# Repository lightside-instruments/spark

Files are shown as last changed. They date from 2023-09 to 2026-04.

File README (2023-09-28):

Spark is a modular open-source hardware platform
base board and enclosure for use as development kit for programmable
network elements.

The project includes KiCAD project with schematics
and PCB layout sources, BOM, and technical documentation for
production of board with 6x SFP+ interfaces and a 96board
extension interface for the connection of a control board
(FPGA or ASIC)  e.g. Ultra96 from Avnet
and up to 3 optional extension boards:
* glue logic for low speed signals from the optical modules
* GNSS controlled oscillators
* other interface boards, sensor boards, etc.

The project includes also technical documentation for production of
mechanical enclosure - 19 inch 1U rack mountable ESD Acrylic box compatibe
with the base board.

The project is published by Lightside Instruments AS
under TAPR Open Hardware License. Read the LICENSE file
for details.

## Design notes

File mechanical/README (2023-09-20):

Use 4mm acrylic sheets and laser cutter

Blue  - Engrave (or make a pocket with CNC) 2 mm deep for the screw heads - all blue circles.
Black - Engrave logo and port numbers with appropriate settings.
Red   - Cut. There is no clearance fit tollerances (openings are 4 mm) so it is your responsibilitto y correct the slack if you need to.

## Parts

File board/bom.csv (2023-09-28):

Reference | Quantity | Identifier | footprint | Value | Tolerance | Voltage | Current | Power | Mfr | Mfr Part # | Notes
P1 | 1 |  | 96boards:Pin_Header_SMD_2x20_Pitch2mm | CONN_02X20 |  |  |  |  | Molex | 87759-4051
P3 | 1 |  | 96boards:61083-063400LF | CONN_02X30 |  |  |  |  | Amphenol | 61083-064400LF
J1_1;J2_1;J3_1;J4_1;J5_1;J6_1 | 6 |  | spark:molex-sfp-plus-747540-101 | SFP+ |  |  |  |  |  | 74754-0101
J1;J2;J3;J4;J5;J6 | 6 |  | spark:molex-sfp-plus-747540-101 | SFP+ |  |  |  |  |  | 74441-0001
J1_2;J2_2;J3_2;J4_2;J5_2;J6_2 | 6 |  | spark:molex-sfp-plus-747540-101 | SFP+ |  |  |  |  |  | 74754-0011
R102;R103;R105;R106;R107;R202;R203;R205;R206;R207;R302;R303;R305;R306;R307;R402;R403;R405;R406;R407;R502;R503;R505;R506;R507;R602;R603;R605;R606;R607;R9 | 31 |  | Resistor_SMD:R_0402_1005Metric | 10K |  |  |  |  |  | CRCW040210K0FKEDC
C102;C104;C101;C103;C202;C204;C201;C203;C302;C304;C301;C303;C402;C404;C401;C403;C502;C504;C501;C503;C602;C604;C601;C603 | 24 |  | Capacitor_SMD:C_0402_1005Metric | 100nF |  |  |  |  |  | 885012205037
J10 | 1 |  | spark:PJ1-021-SMT-TR | Barrel_Jack |  |  |  |  |  | PJ1-021-SMT-TR
L102;L101;L202;L201;L302;L301;L402;L401;L502;L501;L602;L601 | 12 |  | Inductor_SMD:L_1210_3225Metric | 4.7uH |  |  |  |  |  | CM322522-4R7JL
C106;C105;C8;C206;C205;C306;C305;C406;C405;C506;C505;C606;C605 | 13 |  | Capacitor_SMD:C_1210_3225Metric | 22uF |  | >=16V |  |  |  | F931C226MBAAJ6 | TAJB226M016SNJ
D101;D201;D301;D401;D501;D601 | 6 |  | LED_SMD:LED_0402_1005Metric | ADM_LED |  |  |  |  |  | 150040VS73240
R101;R104;R201;R204;R301;R304;R401;R404;R501;R504;R601;R604 | 12 |  | Resistor_SMD:R_0402_1005Metric | 1K |  |  |  |  |  | RR0510P-102-D
D102;D202;D302;D402;D502;D602 | 6 |  | LED_SMD:LED_0402_1005Metric | ALARM_LED |  |  |  |  |  | 150040VS73240
C7 | 1 |  | Capacitor_Tantalum_SMD:CP_EIA-7343-31_Kemet-D | 330uF |  |  |  |  |  | T491D227M016AT
C9 | 1 |  | Capacitor_Tantalum_SMD:CP_EIA-7343-31_Kemet-D | 220uF |  |  |  |  |  | T491D227M016AT
P2 | 1 |  | 96boards:Socket_Strip_SMD_2x20_Pitch2mm | Conn_02x20_Odd_Even |  |  |  |  | Amphenol | 55510-140LF
J8_1;J8_2 | 2 |  | Connector_PinHeader_2.00mm:PinHeader_2x30_P2.00mm_Vertical_SMD | Conn_02x30_Odd_Even |  |  |  |  | Samtec | TMM-130-01-L-D-SM | Or 2x TMM-115-01-L-D-SM
P5;P4 | 2 |  | Connector_PinHeader_2.54mm:PinHeader_2x20_P2.54mm_Vertical_SMD | Conn_02x20_Odd_Even |  |  |  |  | Harwin | M20-7812045
SW2 | 1 |  | Button_Switch_SMD:SW_DIP_SPSTx06_Slide_Omron_A6H-6101_W6.15mm_P1.27mm | SW_DIP_x06 |  |  |  |  |  | A6H-6101
P6 | 1 |  | spark:5177983-2 | CONN_02X30 |  |  |  |  | TE CONNECTIVITY | 1-5177983-2
SW1 | 1 |  | Button_Switch_THT:SW_Tactile_SPST_Angled_PTS645Vx83-2LFS | SW_Push |  |  |  |  |  | PTS645VK582LFS
R1 | 1 |  | Resistor_SMD:R_0402_1005Metric | 13.3K |  |  |  |  |  | ERA-2AEB1332X
U1 | 1 |  |  |  |  |  |  |  |  | LTM4624IY#PBF
U2 | 1 |  | Package_SO:SO-8_3.9x4.9mm_P1.27mm | PCA9306 |  |  |  |  |  | PCA9306D
R3;R4;R6;R7 | 4 |  | Resistor_SMD:R_0402_1005Metric | 4K7 |  |  |  |  |  | CRCW04024K70FKED
R5 | 1 |  | Resistor_SMD:R_0402_1005Metric | 200K |  |  |  |  |  | AC0402FR-7W200KL
J14;J15;J9;J11 | 4 |  | PinSocket_2x07_P2.00mm_Vertical_SMD | Conn_02x07_Odd_Even |  |  |  |  |  | M20-7810745
SW4 | 1 |  | Connector_PinHeader_2.54mm:PinHeader_1x02_P2.54mm_Vertical | SW_DIP_x01 |  |  |  |  |  | 87224-2
R10 | 1 |  | Resistor_SMD:R_0402_1005Metric | 7K15 |  |  |  |  |  | CR0402-FX-7151GLF

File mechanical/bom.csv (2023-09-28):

Reference | Quantity | Mfr | Mfr Part # | Description
M1 | 4 | Wurth | 971080154 | Standoff 8mm_w_6mm_ext_thread
M2 | 10 | Wurth | 970060154 | Standoff Female-Female 6mm
M3 | 4 | Wurth | 971060154 | Standoff 6mm_w_6mm_ext_thread
M4 | 8 | Essentra | 302208059935 | Standoff Female-Female 8mm
M5 | 10 | Wurth | SCR-RSD-DIN7985-4.8-H1-(A2K)-M2,5X4 | Pan head screw M2.5 4mm

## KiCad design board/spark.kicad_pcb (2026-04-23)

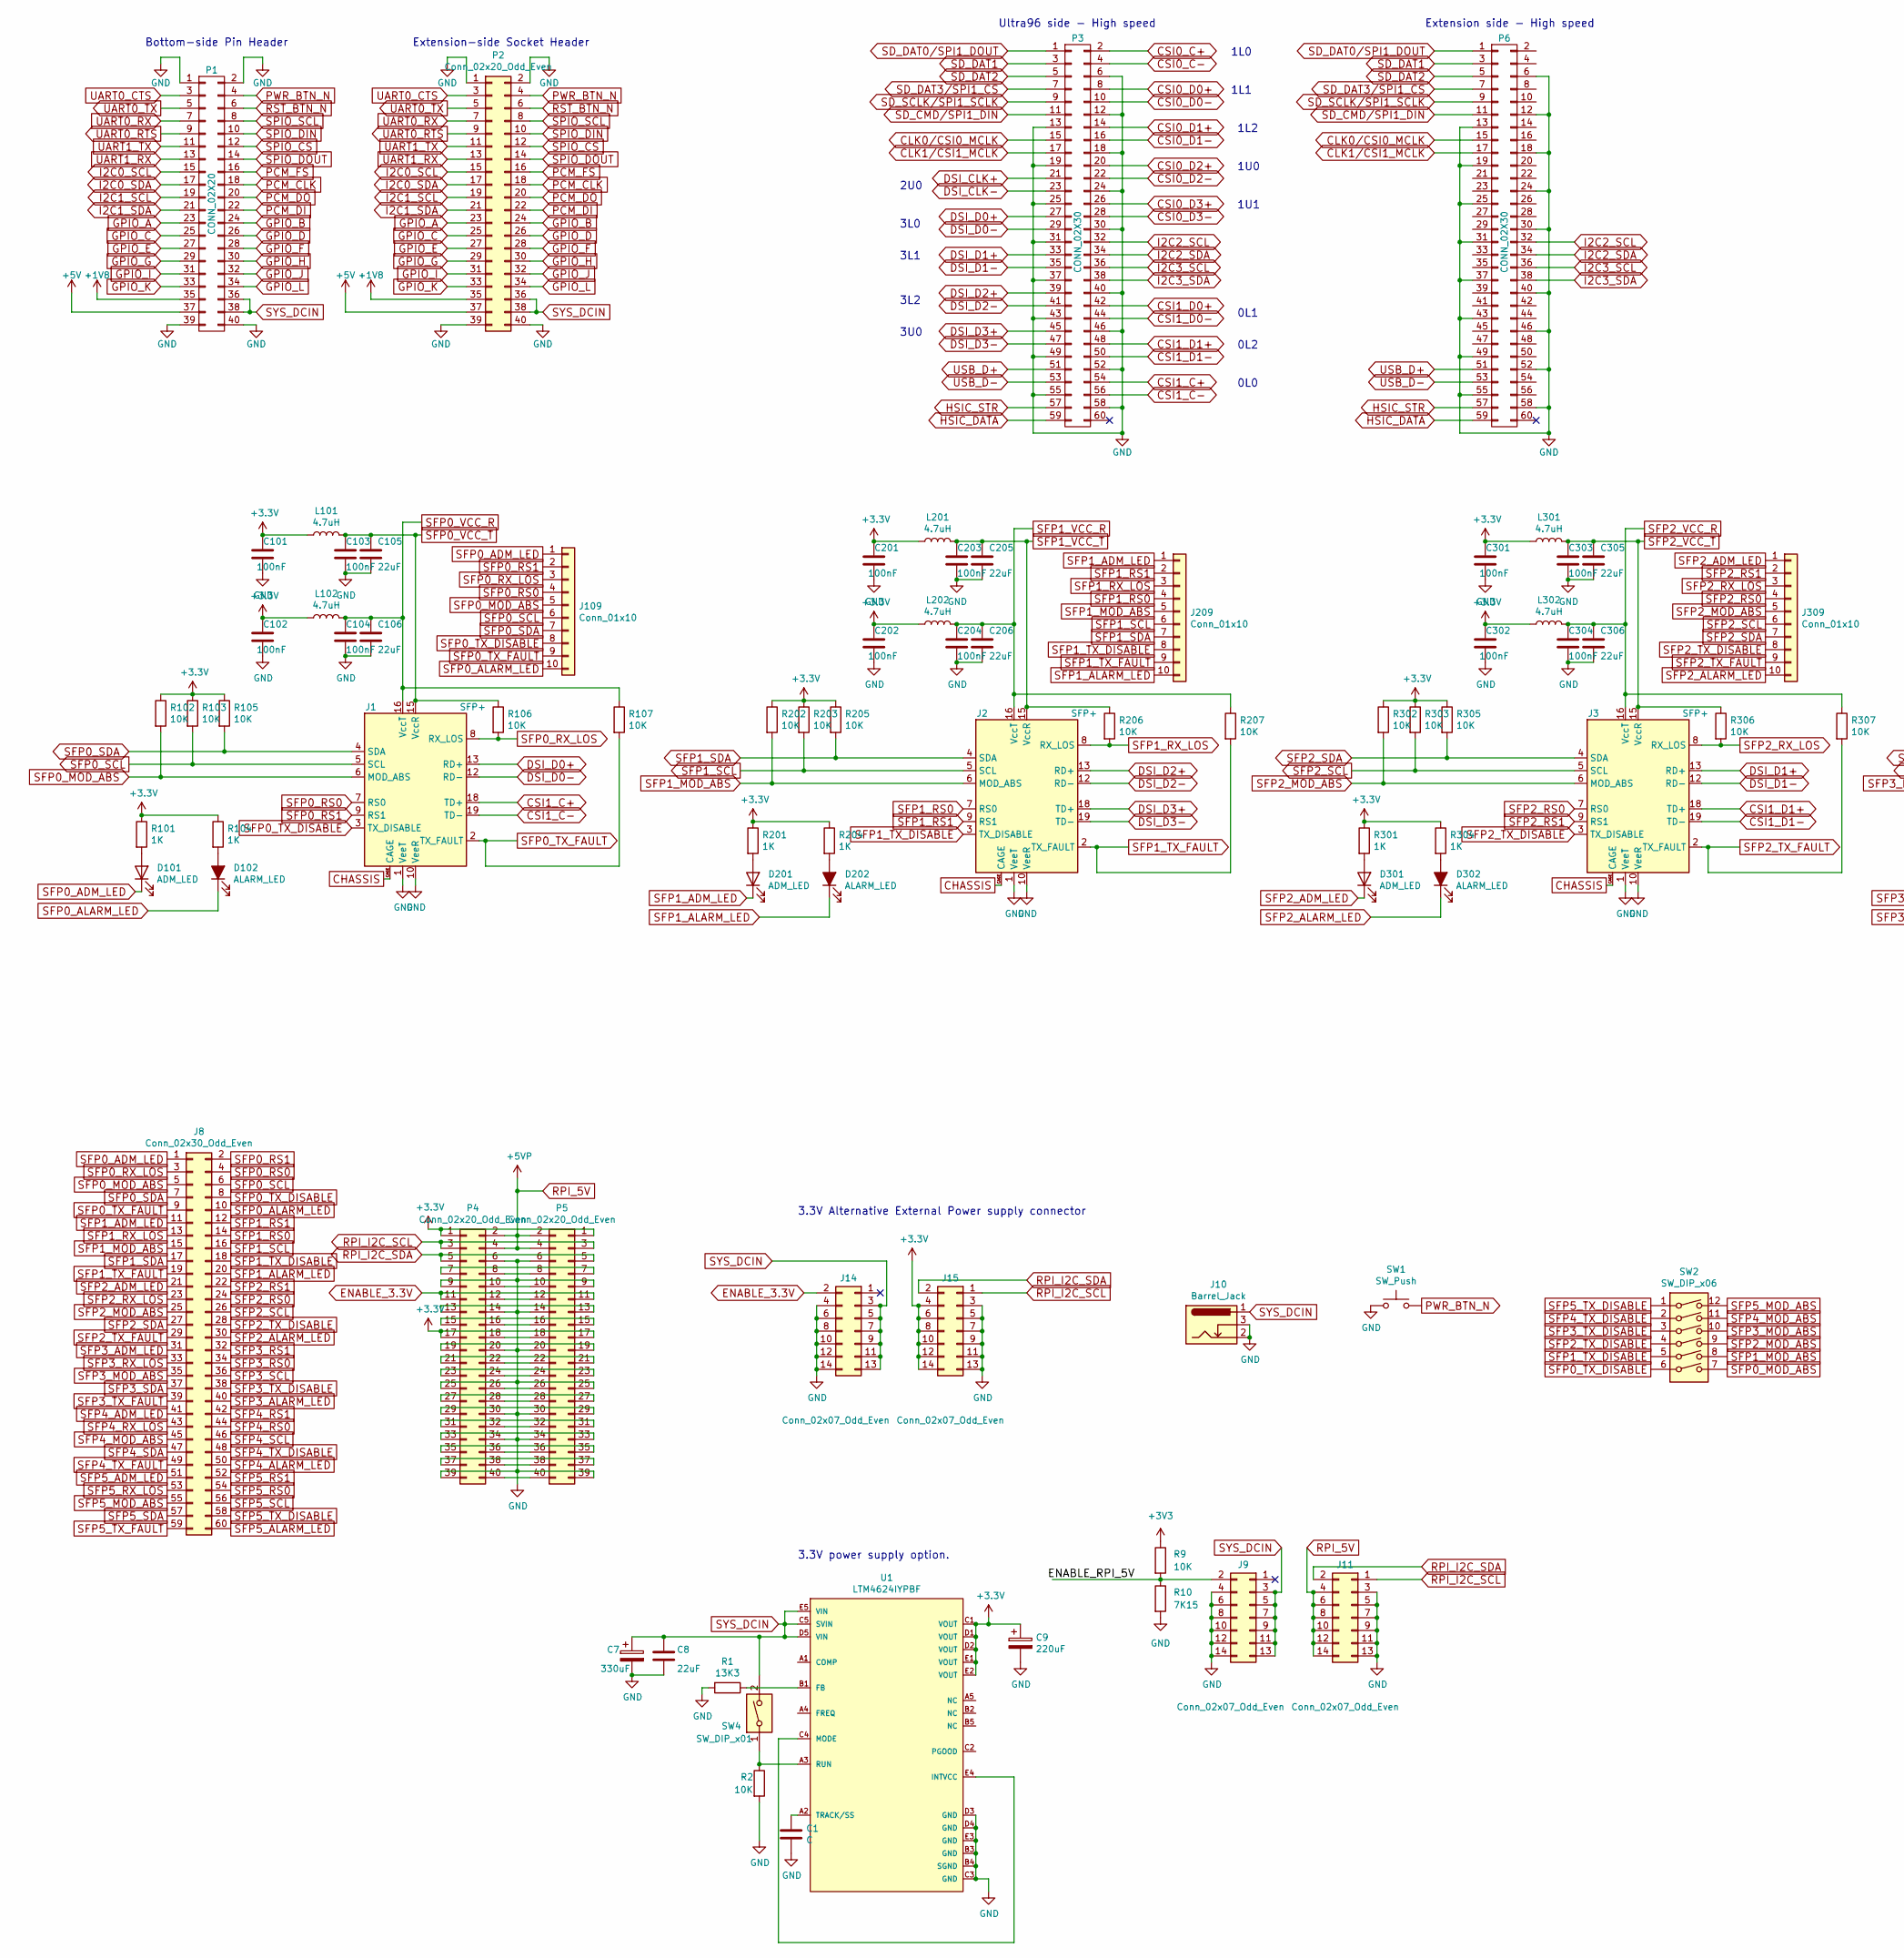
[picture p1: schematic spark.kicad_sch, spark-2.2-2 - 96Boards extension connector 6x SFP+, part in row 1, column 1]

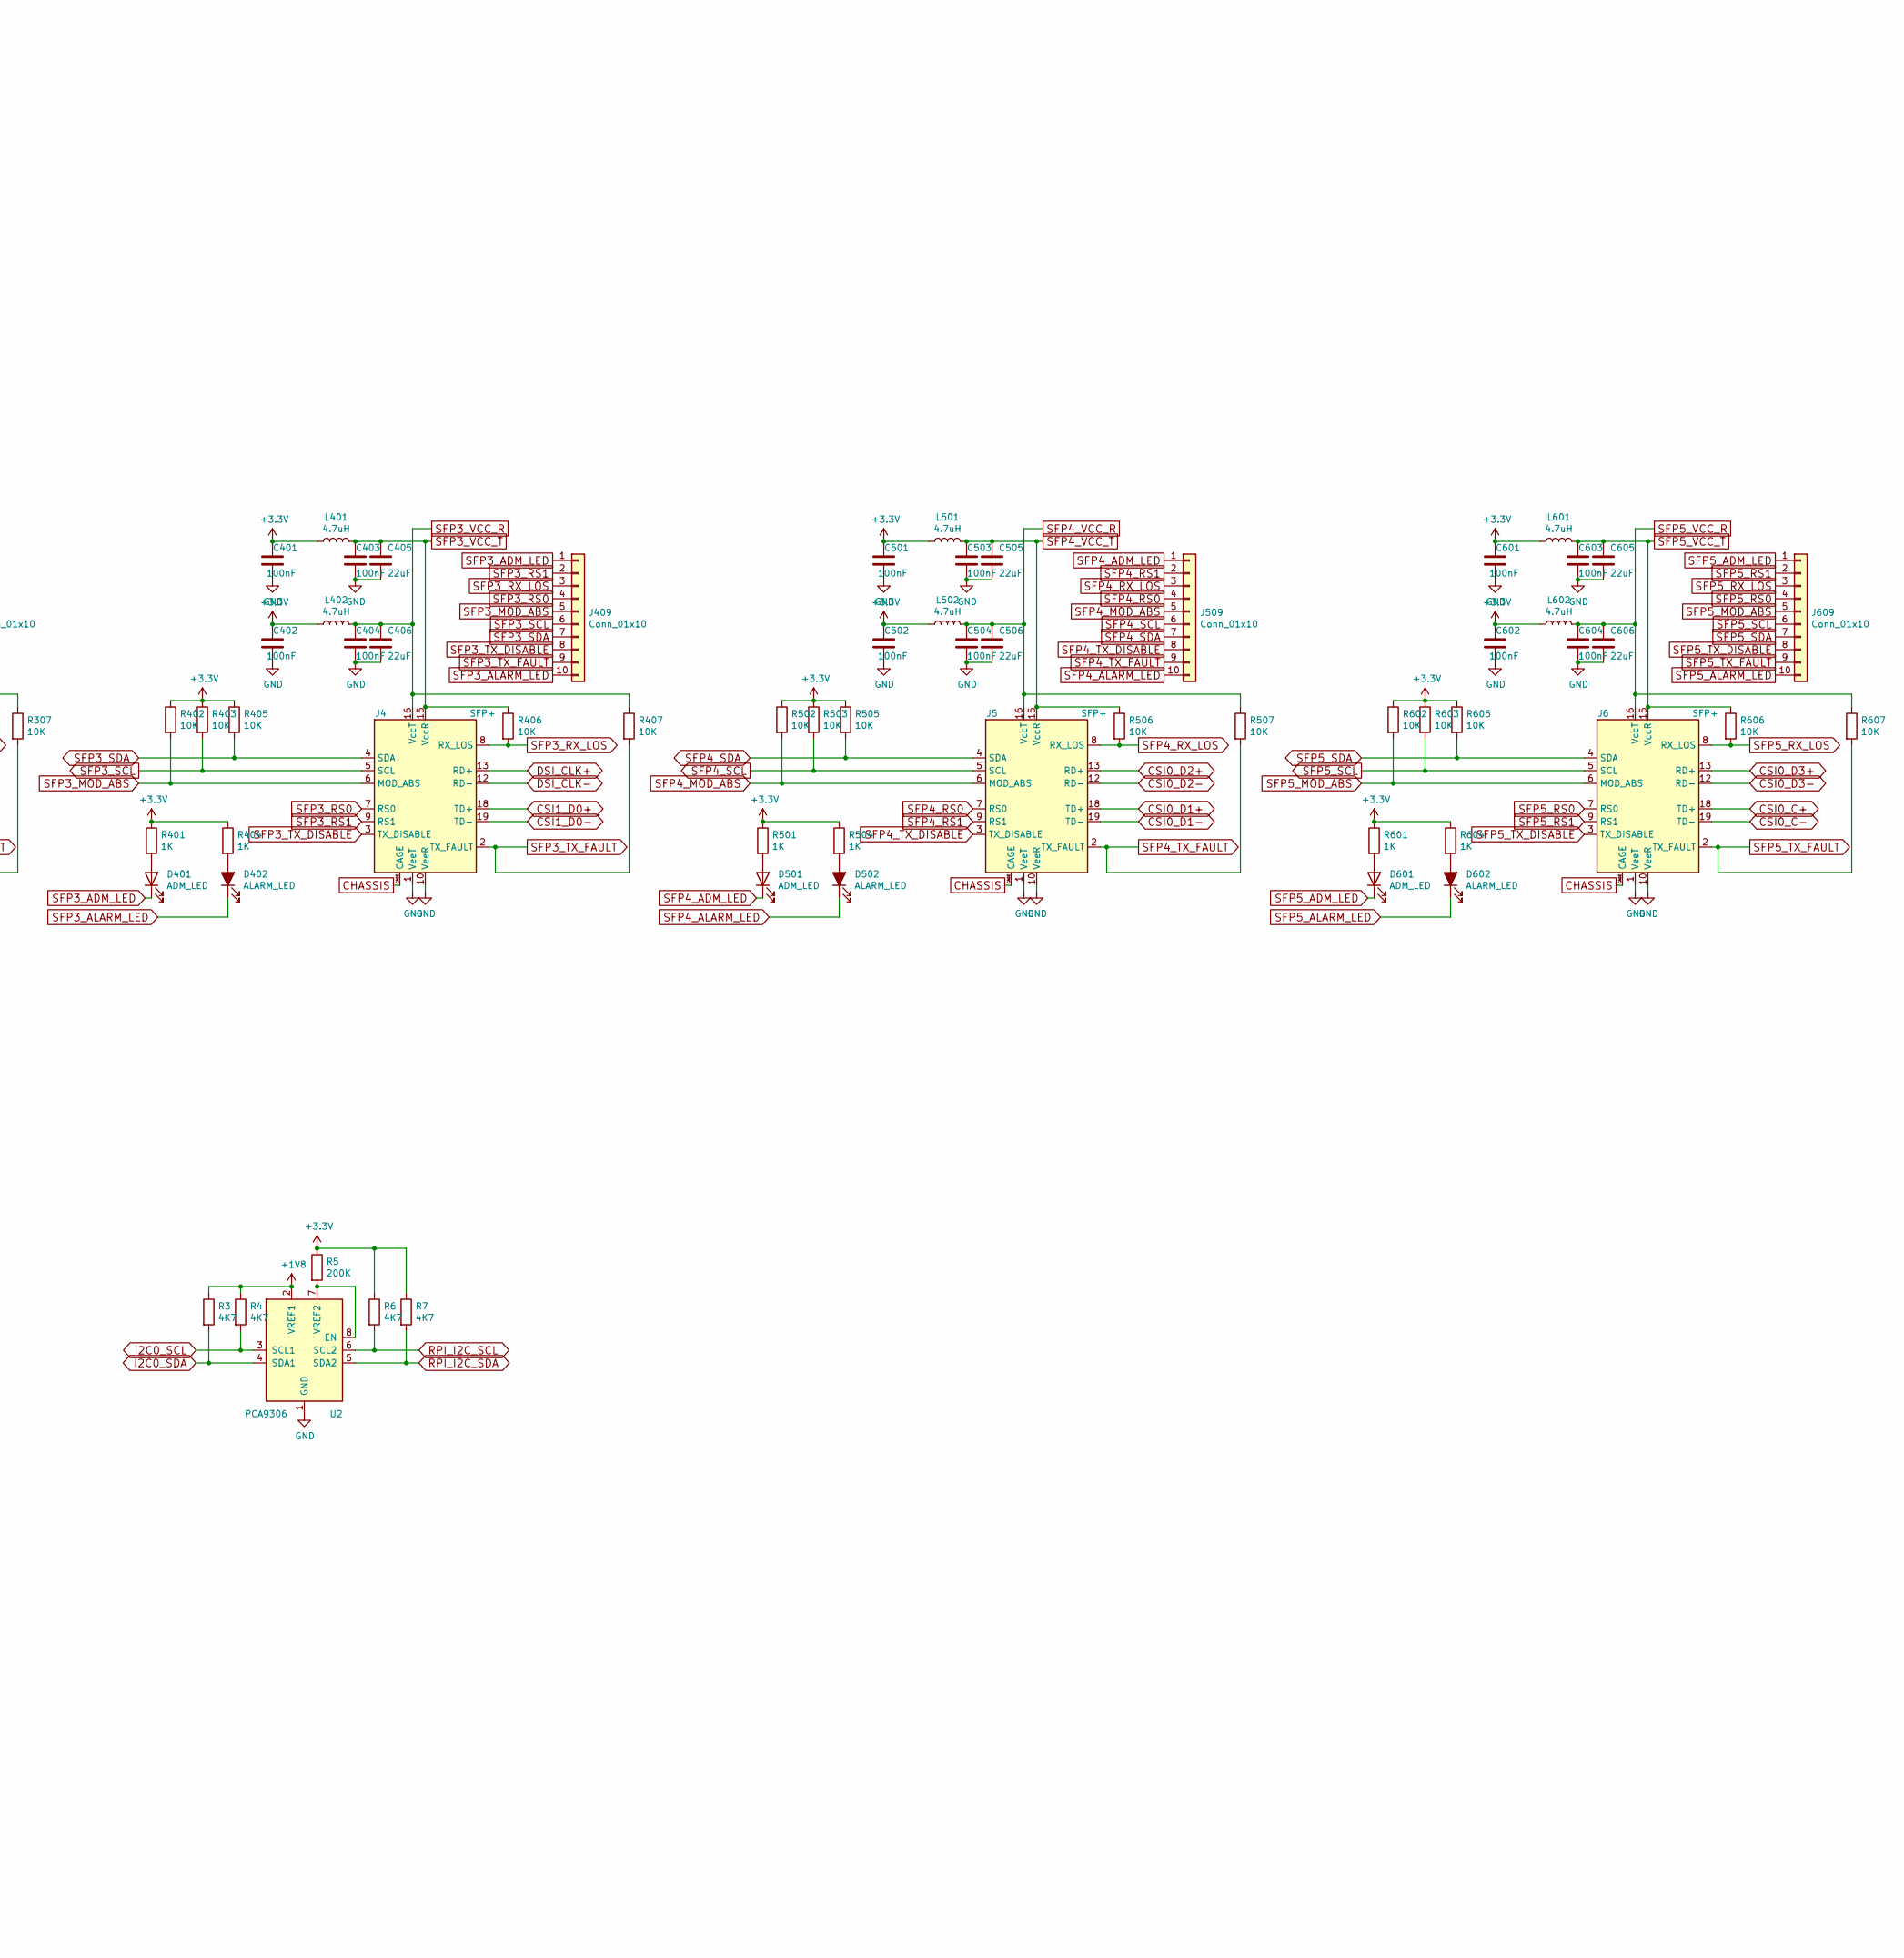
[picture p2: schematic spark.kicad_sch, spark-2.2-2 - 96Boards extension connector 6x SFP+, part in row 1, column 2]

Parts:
C1: C; C_0402_1005Metric
C7: 330uF; CP_EIA-7343-31_Kemet-D
C8, C105, C106, C205, C206, C305, C306, C405, C406, C505, C506, C605, C606: 22uF; CP_EIA-3528-21_Kemet-B; Mfr Part # TAJB226K016TNJ
C9: 220uF; CP_EIA-7343-31_Kemet-D
C101, C102, C103, C104, C201, C202, C203, C204, C301, C302, C303, C304, C401, C402, C403, C404, C501, C502, C503, C504, C601, C602, C603, C604: 100nF; C_0402_1005Metric
D101, D201, D301, D401, D501, D601: ADM_LED; LED_0402_1005Metric
D102, D202, D302, D402, D502, D602: ALARM_LED; LED_0402_1005Metric
J1, J2, J3, J4, J5, J6: SFP+; molex-sfp-plus-747540-101
J8: Conn_02x30_Odd_Even; PinHeader_2x30_P2.00mm_Vertical_SMD
J9, J11, J14, J15: Conn_02x07_Odd_Even; PinSocket_2x07_P2.00mm_Vertical_SMD
J10: Barrel_Jack; PJ1-021-SMT-TR
J109, J209, J309, J409, J509, J609: Conn_01x10; sfp_header
L101, L102, L201, L202, L301, L302, L401, L402, L501, L502, L601, L602: 4.7uH; L_1210_3225Metric
P1: CONN_02X20; Pin_Header_SMD_2x20_Pitch2mm; Mfr Part # 87759-4051
P2: Conn_02x20_Odd_Even; Socket_Strip_SMD_2x20_Pitch2mm_Alignment_Pin
P3: CONN_02X30; 61083-063400LF; Mfr Part # 61083-064400LF
P4, P5: Conn_02x20_Odd_Even; PinSocket_2x20_P2.54mm_Vertical_Inverted_SMD_Alignment_Pin
P6: CONN_02X30; 5177983-2; Mfr Part # 5177983-2
R1: 13K3; R_0402_1005Metric
R2, R9, R102, R103, R105, R106, R107, R202, R203, R205, R206, R207, R302, R303, R305, R306, R307, R402, R403, R405, R406, R407, R502, R503, R505, R506, R507, R602, R603, R605, R606, R607: 10K; R_0402_1005Metric
R3, R4, R6, R7: 4K7; R_0402_1005Metric
R5: 200K; R_0402_1005Metric
R10: 7K15; R_0402_1005Metric
R101, R104, R201, R204, R301, R304, R401, R404, R501, R504, R601, R604: 1K; R_0402_1005Metric
SW1: SW_Push; SW_Tactile_SPST_Angled_PTS645Vx83-2LFS; Mfr Part # PTS645VK582LFS
SW2: SW_DIP_x06; SW_DIP_SPSTx06_Slide_Omron_A6H-6101_W6.15mm_P1.27mm; Mfr Part # A6H-6101
SW4: SW_DIP_x01; PinHeader_1x02_P2.54mm_Vertical
U1: LTM4624IYPBF; Analog_Devices_Inc-BGA-0-05-08-1905_Rev_C-0; output voltage 0.6-5.5V; mouser part number 584-LTM4624IY#PBF; digikey description DC DC CONVERTER 0.6-5.5V 4A
U2: PCA9306; SO-8_3.9x4.9mm_P1.27mm

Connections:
+1V8: P1.35, P2.35, R3.1, R4.1, U2.2 (VREF1)
+5V: P1.37, P2.37
/ENABLE_RPI_5V: J9.2, R9.2, R10.1
CHASSIS: J1.CAGE, J2.CAGE, J3.CAGE, J4.CAGE, J5.CAGE, J6.CAGE
CLK0/CSI0_MCLK: P3.15, P6.15
CLK1/CSI1_MCLK: P3.17, P6.17
CSI0_C+: J6.18 (TD+), P3.2
CSI0_C-: J6.19 (TD-), P3.4
CSI0_D0+: P3.8
CSI0_D0-: P3.10
CSI0_D1+: J5.18 (TD+), P3.14
CSI0_D1-: J5.19 (TD-), P3.16
CSI0_D2+: J5.13 (RD+), P3.20
CSI0_D2-: J5.12 (RD-), P3.22
CSI0_D3+: J6.13 (RD+), P3.26
CSI0_D3-: J6.12 (RD-), P3.28
CSI1_C+: J1.18 (TD+), P3.54
CSI1_C-: J1.19 (TD-), P3.56
CSI1_D0+: J4.18 (TD+), P3.42
CSI1_D0-: J4.19 (TD-), P3.44
CSI1_D1+: J3.18 (TD+), P3.48
CSI1_D1-: J3.19 (TD-), P3.50
DSI_CLK+: J4.13 (RD+), P3.21
DSI_CLK-: J4.12 (RD-), P3.23
DSI_D0+: J1.13 (RD+), P3.27
DSI_D0-: J1.12 (RD-), P3.29
DSI_D1+: J3.13 (RD+), P3.33
DSI_D1-: J3.12 (RD-), P3.35
DSI_D2+: J2.13 (RD+), P3.39
DSI_D2-: J2.12 (RD-), P3.41
DSI_D3+: J2.18 (TD+), P3.45
DSI_D3-: J2.19 (TD-), P3.47
ENABLE_3.3V: J14.2, P4.11, P5.11
GND: C1.2, C7.2, C8.2, C9.2, C101.2, C102.2, C103.2, C104.2, C105.2, C106.2, C201.2, C202.2, C203.2, C204.2, C205.2, C206.2, C301.2, C302.2, C303.2, C304.2, C305.2, C306.2, C401.2, C402.2, C403.2, C404.2, C405.2, C406.2, C501.2, C502.2, C503.2, C504.2, C505.2, C506.2, C601.2, C602.2, C603.2, C604.2, C605.2, C606.2, J1.1 (VeeT), J1.10 (VeeR), J1.11 (VeeR), J1.14 (VeeR), J1.17 (VeeT), J1.20 (VeeT), J2.1 (VeeT), J2.10 (VeeR), J2.11 (VeeR), J2.14 (VeeR), J2.17 (VeeT), J2.20 (VeeT), J3.1 (VeeT), J3.10 (VeeR), J3.11 (VeeR), J3.14 (VeeR), J3.17 (VeeT), J3.20 (VeeT), J4.1 (VeeT), J4.10 (VeeR), J4.11 (VeeR), J4.14 (VeeR), J4.17 (VeeT), J4.20 (VeeT), J5.1 (VeeT), J5.10 (VeeR), J5.11 (VeeR), J5.14 (VeeR), J5.17 (VeeT), J5.20 (VeeT), J6.1 (VeeT), J6.10 (VeeR), J6.11 (VeeR), J6.14 (VeeR), J6.17 (VeeT), J6.20 (VeeT), J9.4, J9.6, J9.8, J9.10, J9.12, J9.14, J10.2, J10.3, J11.3, J11.5, J11.7, J11.9, J11.11, J11.13, J14.4, J14.6, J14.8, J14.10, J14.12, J14.14, J15.3, J15.5, J15.7, J15.9, J15.11, J15.13, P1.1, P1.2, P1.39, P1.40, P2.1, P2.2, P2.39, P2.40, P3.6, P3.12, P3.13, P3.18, P3.19, P3.24, P3.25, P3.30, P3.31, P3.37, P3.40, P3.43, P3.46, P3.49, P3.52, P3.55, P3.58, P4.6, P4.9, P4.14, P4.20, P4.25, P4.30, P4.34, P4.39, P5.6, P5.9, P5.14, P5.20, P5.25, P5.30, P5.34, P5.39, P6.6, P6.12, P6.13, P6.18, P6.19, P6.24, P6.25, P6.30, P6.31, P6.37, P6.40, P6.43, P6.46, P6.49, P6.52, P6.55, P6.58, R1.2, R2.2, R10.2, SW1.1, U1.B3 (GND), U1.B4 (SGND), U1.C3 (GND), U1.D3 (GND), U1.D4 (GND), U1.E3 (GND), U2.1 (GND)
GPIO_A: P1.23, P2.23
GPIO_B: P1.24, P2.24
GPIO_C: P1.25, P2.25
GPIO_D: P1.26, P2.26
GPIO_E: P1.27, P2.27
GPIO_F: P1.28, P2.28
GPIO_G: P1.29, P2.29
GPIO_H: P1.30, P2.30
GPIO_I: P1.31, P2.31
GPIO_J: P1.32, P2.32
GPIO_K: P1.33, P2.33
GPIO_L: P1.34, P2.34
HSIC_DATA: P3.59, P6.59
HSIC_STR: P3.57, P6.57
I2C0_SCL: P1.15, P2.15, R4.2, U2.3 (SCL1)
I2C0_SDA: P1.17, P2.17, R3.2, U2.4 (SDA1)
I2C1_SCL: P1.19, P2.19
I2C1_SDA: P1.21, P2.21
I2C2_SCL: P3.32, P6.32
I2C2_SDA: P3.34, P6.34
I2C3_SCL: P3.36, P6.36
I2C3_SDA: P3.38, P6.38
unnamed: C1.1, U1.A2 (TRACK/SS)
unnamed: D101.2 (A), R101.2
unnamed: D102.2 (A), R104.2
unnamed: D201.2 (A), R201.2
unnamed: D202.2 (A), R204.2
unnamed: D301.2 (A), R301.2
unnamed: D302.2 (A), R304.2
unnamed: D401.2 (A), R401.2
unnamed: D402.2 (A), R404.2
unnamed: D501.2 (A), R501.2
unnamed: D502.2 (A), R504.2
unnamed: D601.2 (A), R601.2
unnamed: D602.2 (A), R604.2
unnamed: P4.7, P5.7
unnamed: P4.8, P5.8
unnamed: P4.10, P5.10
unnamed: P4.12, P5.12
unnamed: P4.13, P5.13
unnamed: P4.15, P5.15
unnamed: P4.16, P5.16
unnamed: P4.18, P5.18
unnamed: P4.19, P5.19
unnamed: P4.21, P5.21
unnamed: P4.22, P5.22
unnamed: P4.23, P5.23
unnamed: P4.24, P5.24
unnamed: P4.26, P5.26
unnamed: P4.27, P5.27
unnamed: P4.28, P5.28
unnamed: P4.29, P5.29
unnamed: P4.31, P5.31
unnamed: P4.32, P5.32
unnamed: P4.33, P5.33
unnamed: P4.35, P5.35
unnamed: P4.36, P5.36
unnamed: P4.37, P5.37
unnamed: P4.38, P5.38
unnamed: P4.40, P5.40
unnamed: R1.1, U1.B1 (FB)
unnamed: R2.1, SW4.1, U1.A3 (RUN)
unnamed: R5.2, U2.7 (VREF2), U2.8 (EN)
unnamed: U1.C4 (MODE), U1.E4 (INTVCC)
PCM_CLK: P1.18, P2.18
PCM_DI: P1.22, P2.22
PCM_DO: P1.20, P2.20
PCM_FS: P1.16, P2.16
PWR_BTN_N: P1.4, P2.4, SW1.2
RPI_5V: J11.4, J11.6, J11.8, J11.10, J11.12, J11.14, P4.2, P4.4, P5.2, P5.4
RPI_I2C_SCL: J11.1, J15.1, P4.3, P5.3, R6.2, U2.6 (SCL2)
RPI_I2C_SDA: J11.2, J15.2, P4.5, P5.5, R7.2, U2.5 (SDA2)
RST_BTN_N: P1.6, P2.6
SD_CMD/SPI1_DIN: P3.11, P6.11
SD_DAT0/SPI1_DOUT: P3.1, P6.1
SD_DAT1: P3.3, P6.3
SD_DAT2: P3.5, P6.5
SD_DAT3/SPI1_CS: P3.7, P6.7
SD_SCLK/SPI1_SCLK: P3.9, P6.9
SFP0_ADM_LED: D101.1 (K), J8.1, J109.1
SFP0_ALARM_LED: D102.1 (K), J8.10, J109.10
SFP0_MOD_ABS: J1.6 (MOD_ABS), J8.5, J109.5, R102.2, SW2.7
SFP0_RS0: J1.7 (RS0), J8.4, J109.4
SFP0_RS1: J1.9 (RS1), J8.2, J109.2
SFP0_RX_LOS: J1.8 (RX_LOS), J8.3, J109.3, R106.2
SFP0_SCL: J1.5 (SCL), J8.6, J109.6, R103.2
SFP0_SDA: J1.4 (SDA), J8.7, J109.7, R105.2
SFP0_TX_DISABLE: J1.3 (TX_DISABLE), J8.8, J109.8, SW2.6
SFP0_TX_FAULT: J1.2 (TX_FAULT), J8.9, J109.9, R107.2
SFP0_VCC_R: C104.1, C106.1, J1.16 (VccT), L102.2, R107.1
SFP0_VCC_T: C103.1, C105.1, J1.15 (VccR), L101.2, R106.1
SFP1_ADM_LED: D201.1 (K), J8.11, J209.1
SFP1_ALARM_LED: D202.1 (K), J8.20, J209.10
SFP1_MOD_ABS: J2.6 (MOD_ABS), J8.15, J209.5, R202.2, SW2.8
SFP1_RS0: J2.7 (RS0), J8.14, J209.4
SFP1_RS1: J2.9 (RS1), J8.12, J209.2
SFP1_RX_LOS: J2.8 (RX_LOS), J8.13, J209.3, R206.2
SFP1_SCL: J2.5 (SCL), J8.16, J209.6, R203.2
SFP1_SDA: J2.4 (SDA), J8.17, J209.7, R205.2
SFP1_TX_DISABLE: J2.3 (TX_DISABLE), J8.18, J209.8, SW2.5
SFP1_TX_FAULT: J2.2 (TX_FAULT), J8.19, J209.9, R207.2
SFP1_VCC_R: C204.1, C206.1, J2.16 (VccT), L202.2, R207.1
SFP1_VCC_T: C203.1, C205.1, J2.15 (VccR), L201.2, R206.1
SFP2_ADM_LED: D301.1 (K), J8.21, J309.1
SFP2_ALARM_LED: D302.1 (K), J8.30, J309.10
SFP2_MOD_ABS: J3.6 (MOD_ABS), J8.25, J309.5, R302.2, SW2.9
SFP2_RS0: J3.7 (RS0), J8.24, J309.4
SFP2_RS1: J3.9 (RS1), J8.22, J309.2
SFP2_RX_LOS: J3.8 (RX_LOS), J8.23, J309.3, R306.2
SFP2_SCL: J3.5 (SCL), J8.26, J309.6, R303.2
SFP2_SDA: J3.4 (SDA), J8.27, J309.7, R305.2
SFP2_TX_DISABLE: J3.3 (TX_DISABLE), J8.28, J309.8, SW2.4
SFP2_TX_FAULT: J3.2 (TX_FAULT), J8.29, J309.9, R307.2
SFP2_VCC_R: C304.1, C306.1, J3.16 (VccT), L302.2, R307.1
SFP2_VCC_T: C303.1, C305.1, J3.15 (VccR), L301.2, R306.1
SFP3_ADM_LED: D401.1 (K), J8.31, J409.1
SFP3_ALARM_LED: D402.1 (K), J8.40, J409.10
SFP3_MOD_ABS: J4.6 (MOD_ABS), J8.35, J409.5, R402.2, SW2.10
SFP3_RS0: J4.7 (RS0), J8.34, J409.4
SFP3_RS1: J4.9 (RS1), J8.32, J409.2
SFP3_RX_LOS: J4.8 (RX_LOS), J8.33, J409.3, R406.2
SFP3_SCL: J4.5 (SCL), J8.36, J409.6, R403.2
SFP3_SDA: J4.4 (SDA), J8.37, J409.7, R405.2
SFP3_TX_DISABLE: J4.3 (TX_DISABLE), J8.38, J409.8, SW2.3
SFP3_TX_FAULT: J4.2 (TX_FAULT), J8.39, J409.9, R407.2
SFP3_VCC_R: C404.1, C406.1, J4.16 (VccT), L402.2, R407.1
SFP3_VCC_T: C403.1, C405.1, J4.15 (VccR), L401.2, R406.1
SFP4_ADM_LED: D501.1 (K), J8.41, J509.1
SFP4_ALARM_LED: D502.1 (K), J8.50, J509.10
SFP4_MOD_ABS: J5.6 (MOD_ABS), J8.45, J509.5, R502.2, SW2.11
SFP4_RS0: J5.7 (RS0), J8.44, J509.4
SFP4_RS1: J5.9 (RS1), J8.42, J509.2
SFP4_RX_LOS: J5.8 (RX_LOS), J8.43, J509.3, R506.2
SFP4_SCL: J5.5 (SCL), J8.46, J509.6, R503.2
SFP4_SDA: J5.4 (SDA), J8.47, J509.7, R505.2
SFP4_TX_DISABLE: J5.3 (TX_DISABLE), J8.48, J509.8, SW2.2
SFP4_TX_FAULT: J5.2 (TX_FAULT), J8.49, J509.9, R507.2
SFP4_VCC_R: C504.1, C506.1, J5.16 (VccT), L502.2, R507.1
SFP4_VCC_T: C503.1, C505.1, J5.15 (VccR), L501.2, R506.1
SFP5_ADM_LED: D601.1 (K), J8.51, J609.1
SFP5_ALARM_LED: D602.1 (K), J8.60, J609.10
SFP5_MOD_ABS: J6.6 (MOD_ABS), J8.55, J609.5, R602.2, SW2.12
SFP5_RS0: J6.7 (RS0), J8.54, J609.4
SFP5_RS1: J6.9 (RS1), J8.52, J609.2
SFP5_RX_LOS: J6.8 (RX_LOS), J8.53, J609.3, R606.2
SFP5_SCL: J6.5 (SCL), J8.56, J609.6, R603.2
SFP5_SDA: J6.4 (SDA), J8.57, J609.7, R605.2
SFP5_TX_DISABLE: J6.3 (TX_DISABLE), J8.58, J609.8, SW2.1
SFP5_TX_FAULT: J6.2 (TX_FAULT), J8.59, J609.9, R607.2
SFP5_VCC_R: C604.1, C606.1, J6.16 (VccT), L602.2, R607.1
SFP5_VCC_T: C603.1, C605.1, J6.15 (VccR), L601.2, R606.1
SPIO_CS: P1.12, P2.12
SPIO_DIN: P1.10, P2.10
SPIO_DOUT: P1.14, P2.14
SPIO_SCL: P1.8, P2.8
SYS_DCIN: C7.1, C8.1, J9.3, J9.5, J9.7, J9.9, J9.11, J9.13, J10.1, J14.3, J14.5, J14.7, J14.9, J14.11, J14.13, P1.36, P1.38, P2.36, P2.38, SW4.2, U1.C5 (SVIN), U1.D5 (VIN), U1.E5 (VIN)
UART0_CTS: P1.3, P2.3
UART0_RTS: P1.9, P2.9
UART0_RX: P1.7, P2.7
UART0_TX: P1.5, P2.5
UART1_RX: P1.13, P2.13
UART1_TX: P1.11, P2.11
USB_D+: P3.51, P6.51
USB_D-: P3.53, P6.53

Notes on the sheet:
1U1
3.3V power supply option.
Extension side - High speed
1L1
1U0
3L2
0L2
3L1
3U0
Ultra96 side - High speed
Bottom-side Pin Header
2U0
Extension-side Socket Header
3.3V Alternative External Power supply connector
0L1
3L0
0L0
1L2
1L0

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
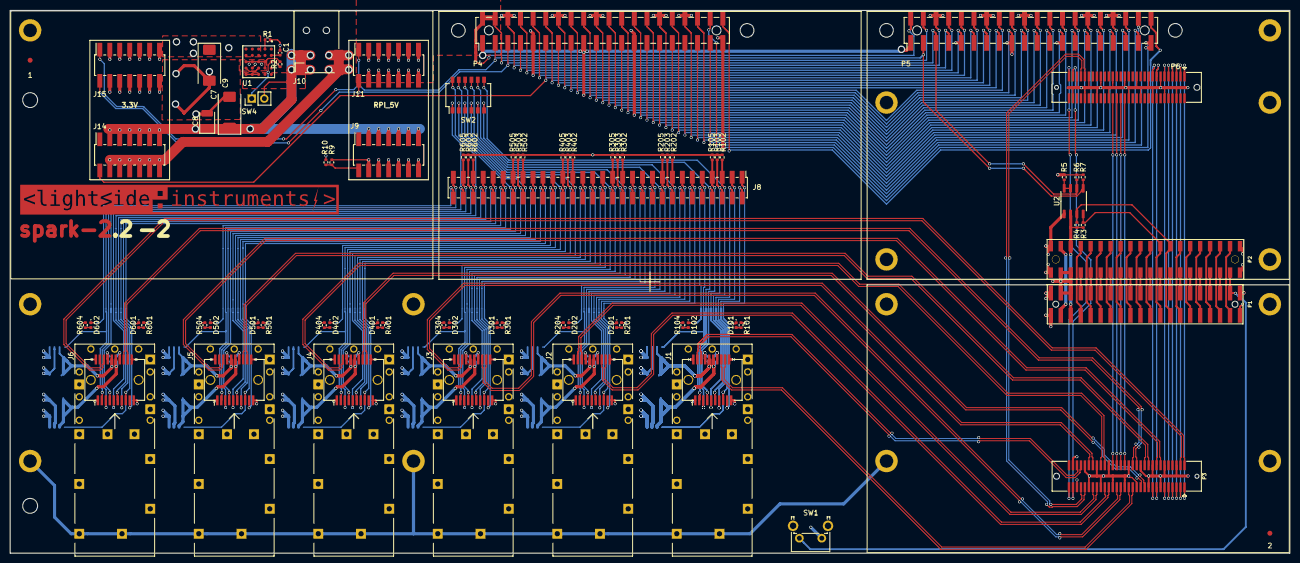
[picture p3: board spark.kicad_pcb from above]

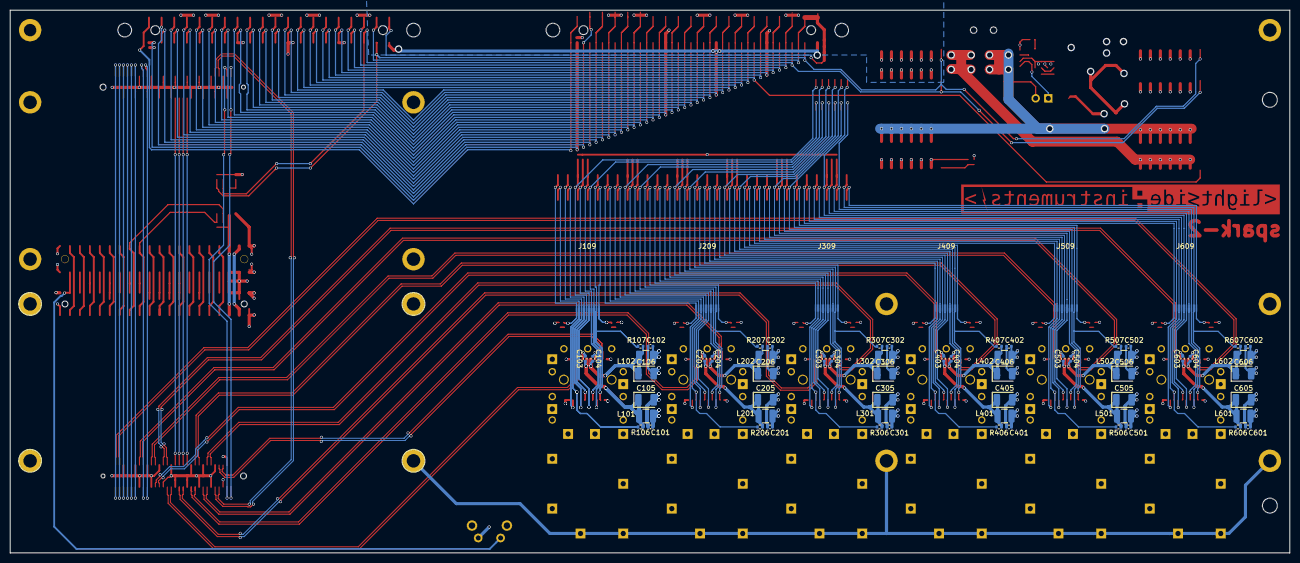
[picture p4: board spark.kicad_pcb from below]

Board: 4 copper layers, 257.0 x 109.0 mm, 146 parts (66 on the bottom side), 197 nets.

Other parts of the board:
1, 2: Fiducial_1mm_Mask3mm

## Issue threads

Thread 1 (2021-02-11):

Extension module board with 2x "Click board" interfaces and Raspberry Pi Hat compatible header

lightside-instruments, 2021-02-11:
In a common usecase one needs an extension board for interfacing with the  6x SFP+ low speed signals (which are currently mapped to Raspberry Pi Hat compatible 2x20 header ) and another one for the aes-acc-u96-me-mez + MIKROE-2670 GPS clock synchronization.

A single board to extend the aes-acc-u96-me-mez design with Raspberry Pi Hat compatible through-hole header can solve the issue of keeping the vertical stack inside the 1U vertical limit.

The design files can be placed under board/modules/click-and-pi

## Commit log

2023-09-14 Release 2.0-12
    [spark.kicad_pcb, spark.kicad_sch, spark.sch]
2023-09-20 Release 2.0-13
    [bom.csv, spark.kicad_pcb, spark.kicad_sch]
2023-09-22 Release 2.1
    [bom.csv, spark.kicad_pcb, spark.kicad_sch]
2023-09-28 Release 2.2
    [bom.csv, spark.kicad_pcb, spark.kicad_sch]
2024-05-27 Release 2.2-1
    [spark.kicad_pcb, spark.kicad_sch]
2024-05-27 Release 2.2-2
    [spark.kicad_pcb, spark.kicad_sch]
2026-04-23 Release 2.2-4
    [spark.kicad_pcb, spark.kicad_sch]
2026-09-27 Release 2.2-5
    [bom.csv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]
